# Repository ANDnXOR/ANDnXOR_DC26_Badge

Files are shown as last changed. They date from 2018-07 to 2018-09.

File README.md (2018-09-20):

# AND!XOR DC26 Indie Badge

All files related to the badge are posted here. For now we are only releasing the SD card image as well as any updates to the .bin file (for updates to the core badge itself).

To create a new SD card, format the card with FAT32 then copy the contents of SD/ to the SD card.

*Note: due to the large size of some files, git lfs is required: https://git-lfs.github.com/ *

## LULZCODE Support for Atom Editor ##

LULZCODE is supported by Atom using our plugin: https://atom.io/packages/atom-lulzcode

It is only tested to work on Linux as Windows does not play well with YMODEM from the commandline. At AND!XOR we've been using Linux as our daily-driver since the year of the Linux Desktop anyways. And so should you.
 
## Firmware Updates ##

This year's badge is capable of flashing itself over the air (OTA) or from SD card. OTAs will be available at DEF CON at select locations, times and locations TBD.

To update your firmware manually, place `mrmeeseeks.enc.bin` and `mrmeeseeks.enc.bin.sha256` in the root directory of your SD Card. Place the SD Card back into the badge. The badge may reboot itself or you will need to manually restart it to start the OTA process.

The badge's eye will _very slowly_ blink as it flashes itself. When complete, the badge will restart and the files will be deleted. The process should take 1 to 2 minutes. 

To check the firmware version, go to *System --> About*

*NOTE: It is pointless to check the hash in the `.sha256` file. It will not match.*

## Changelog ##

#### v1.3 ####
* Minor tweaks to further improve SD reliability / avoid corruption.

#### v1.2 ####
* Huge SD stability improvements. Bad blocks no longer crash bling, but will drop frames. Bad blocks are still not readable but we no longer crash.
* Updated to latest ESP-IDF 3.1 beta
* Improved usability of menus based on user feedback
* Fixed ADC not-calibrated (battery voltage was incorrect)
* Added BLE peer hello for Trans Ionospheric badge

#### v1.1 ####
* Stability improvements to the SD Card driver at the expense of some FPS
* Minor improvements to usability of the Pick Name UI
* Thank you to the beta testers for the honest and plentiful feedback of SD card issues. Quality of the SD cards we provided with the badges is poor :( but this firmware update should ensure that good SD cards work properly

#### v1.0 ####
* Initial Release, all Kickstarters received this version

## Known Issues ##

* Voltage displayed on main menu title bar is not accurate
* SD Cards with many bad sectors crash badge (reboot) or exit bling to menu
* Some CHIP8 games do not run

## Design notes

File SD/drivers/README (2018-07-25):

For convenience, drivers for the USB to Serial IC we used are contained here. In the event you do trust us, this will save you some time downloading drivers yourself.

If you don't trust us, you shouldn't, download the CP2102N drivers from silabs.

For Linux, drivers are included. Just need appropriate permissions on the /dev/tty* device and a udev rule. See: https://www.silabs.com/community/interface/knowledge-base.entry.html/2016/06/06/fixed_tty_deviceass-XzTf

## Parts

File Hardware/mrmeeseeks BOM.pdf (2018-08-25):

# AND!XOR DC26 BOM

Designator | Package | Quantity | Designation
U38 | ESP32-WROVER | 1 ESP32 WROVER
R11 | 0402 | 11M Ω
C1,C3,C5,C7,C8,C10,C 18,C19,C22,C25,C26 | 0402 | 110.1uF
C2,C4,C6,C9,C11,C12, C15,C16,C17,C20,C24, C28,C29 | 1206 | 1310uF
C13,C14,C21,C23,C27 | 0402 | 51uF
CON1 | MicroSD | 1 Micro SD Holder
L1 | 1008 | 1 CVH252009-4R7M
R2,R3,R6,R13,R27,R28 ,R26,R16,R22,R23,R24, R25 | 0402 | 1210k Ω
R5 | 0402 | 1470 Ω
R14 | 0402 | 120k Ω
R15 | 0402 | 1100k Ω
Q1,Q2 | SOT-23 | 2 MMBT3904
U36 | SOT-23-6 | 1 AAT1217IGU-3.3-T1
U37 | SOT-223 | 1LM1117IMP-3.3/NOPB
SW10 | JS202011SCQN | 1JS202011SCQN
J1 | MicroUSB | 110118193-0001LF
D1 | 0805 | 1 Red LED
SW1,SW2,SW3,SW4,S W5,SW6,SW7 | 4.2MM | 7 PTS810 SJK
U41 | LGA-12_2x2mm_Pitch0.5mm | 1LIS2DE12TR
U15 | QFN-28-1EP_5x5mm_Pitch0.5mm | 1 CP2102N-A01-GQFN28
U39 | QFN-40-1EP_5x5mm_Pitch0.4mm | 1IS31FL3736
U5 | QFN20 | 1 SLG4AD42405
R12,R7,R8,R9,R10 | 0402 | 51k Ω
E3,E1,E2 | SOD-882L | 3LXES15AAA1-133
R18 | 0402 | 122.1k Ω
R19 | 0402 | 147.5k Ω
BT1 | 2AA-Holder-12BH321P-GR | 112BH321P-GR
U10,U4,U8,U17,U28,U9 ,U13,U19,U23,U27,U31, U35,U3,U2,U18,U22,U2 6,U30,U34,U7,U1,U11, U20,U21,U25,U29,U33, U6,U16,U24,U12 | 1616 | 31LED RGB Common Anode
R17 | 0805 | 1100 Ω
J4 | 15 pin – custom | 1tm020GDHG02

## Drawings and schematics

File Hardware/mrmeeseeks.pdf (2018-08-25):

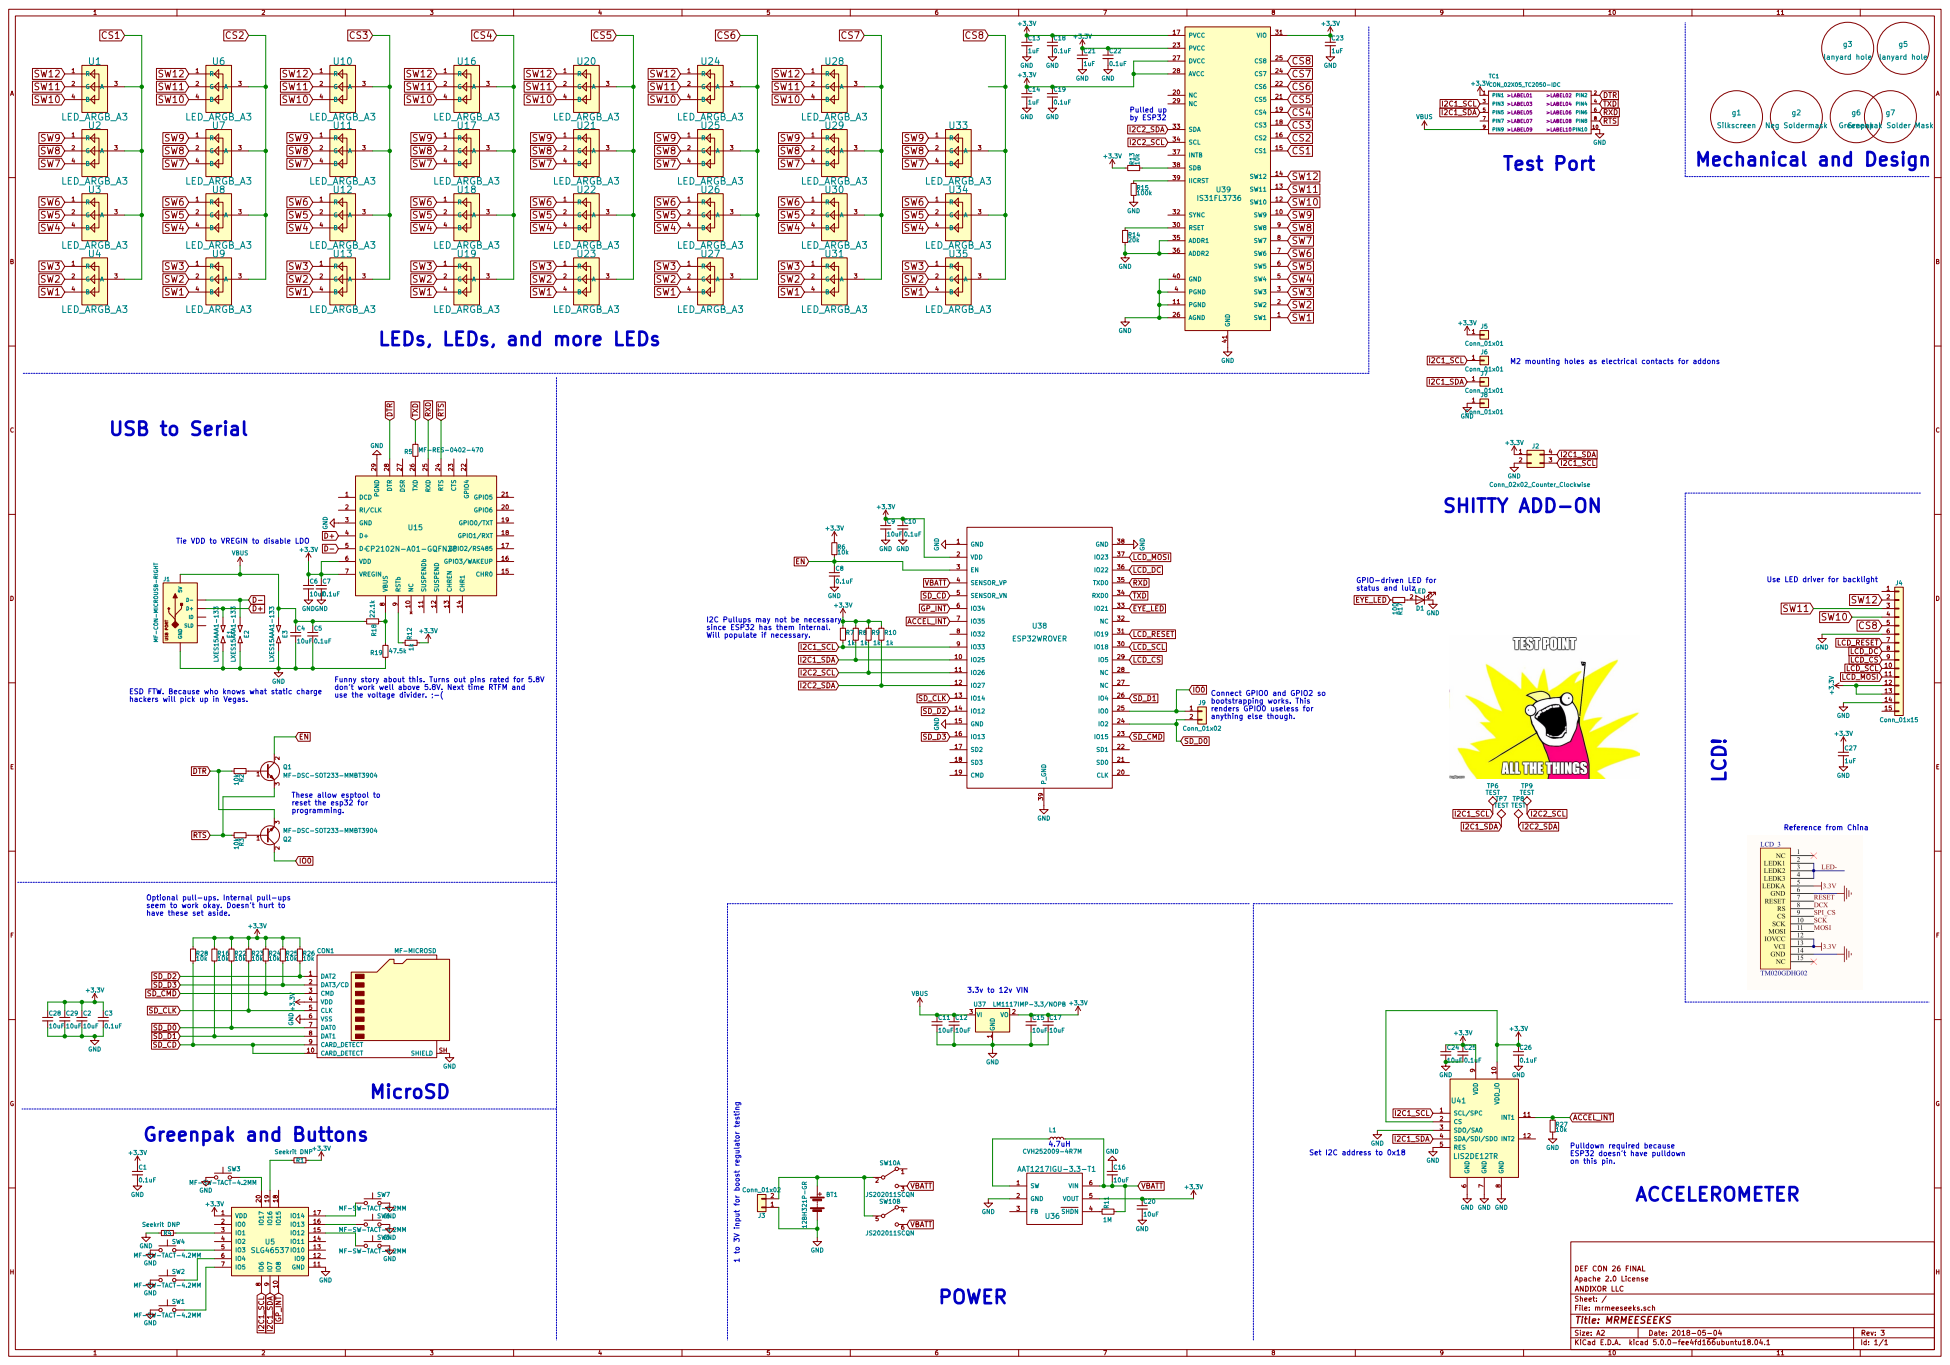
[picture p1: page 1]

+3.3V GND LEDs, LEDs, and more LEDs

+3.3V GND SHITTY ADD-ON

9 U15 CP2102N-A01-GQFN28 R18 22.1k R19 47.5k +3.3V GNDGND Tie VDD to VREGIN to disable LDO

J1 MF-CON-MICROUSB-RIGHT

I2C Pullups may not be necessary
since ESP32 has them internal.

LCD_SCL 1 to 3V input for boost regulator testing

Funny story about this. Turns out pins rated for 5.8V
don't work well above 5.8V. Next time RTFM and use the voltage divider. ;-(

ESD FTW. Because who knows what static charge
hackers will pick up in Vegas.

These allow esptool to
reset the esp32 for

10k +3.3V Optional pull-ups. Internal pull-ups
seem to work okay. Doesn't hurt to
have these set aside.

R1 Seekrit DNP R4 Seekrit DNP GND

GND Set I2C address to 0x18

Apache 2.0 License DEF CON 26 FINAL

File: mrmeeseeks.sch Sheet: / AND!XOR LLC

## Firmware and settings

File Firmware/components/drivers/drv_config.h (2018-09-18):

/*****************************************************************************
 * Made with beer and late nights in California.
 *
 * (C) Copyright 2017-2018 AND!XOR LLC (http://andnxor.com/).
 *
 * PROPRIETARY AND CONFIDENTIAL UNTIL AUGUST 7th, 2018 then,
 *
 * Licensed under the Apache License, Version 2.0 (the "License");
 * you may not use this file except in compliance with the License.
 * You may obtain a copy of the License at
 *
 *     http://www.apache.org/licenses/LICENSE-2.0
 *
 * Unless required by applicable law or agreed to in writing, software
 * distributed under the License is distributed on an "AS IS" BASIS,
 * WITHOUT WARRANTIES OR CONDITIONS OF ANY KIND, either express or implied.
 * See the License for the specific language governing permissions and
 * limitations under the License.
 *
 * ADDITIONALLY:
 * If you find this source code useful in anyway, use it in another electronic
 * conference badge, or just think it's neat. Consider buying us a beer
 * (or two) and/or a badge (or two). We are just as obsessed with collecting
 * badges as we are in making them.
 *
 * Contributors:
 * 	@andnxor
 * 	@zappbrandnxor
 * 	@hyr0n1
 * 	@exc3ls1or
 * 	@lacosteaef
 * 	@bitstr3m
 *****************************************************************************/
#include "system.h"

#ifndef BUILD_DRV_CONFIG_H_
#define BUILD_DRV_CONFIG_H_

#define LCD_PIN_MOSI 23
#define LCD_PIN_CLK 18
#define LCD_PIN_CS 5
#define LCD_PIN_DC 22

#ifndef CONFIG_BADGE_TYPE_STANDALONE
#define LCD_PIN_RST 19
#define LED_EYE_PIN 21
#endif

#define I2C_1_FREQ_HZ 400000
#define I2C_2_FREQ_HZ 400000
#define I2C_1_SDA 25
#define I2C_1_SCL 33
#define I2C_2_SDA 27
#define I2C_2_SCL 26
#define I2C_MASTER_RX_BUF_DISABLE 0
#define I2C_MASTER_TX_BUF_DISABLE 0
#define I2C_MAX_DELAY 100

#define LED_I2C_ADDR ISSI_ADDR_DEFAULT
#define LED_I2C_MASTER_NUM I2C_NUM_1

#define ACCEL_I2C_ADDR_1 0x18
#define ACCEL_I2C_ADDR_2 0x19
#define ACCEL_I2C_MASTER_NUM I2C_NUM_0
#define ACCEL_ISR_GPIO 35
#define ACCEL_ISR_GPIO_MASK GPIO_SEL_35

#define GREENPAK_I2C_ADDR 0x30
#define GREENPAK_I2C_MASTER_NUM I2C_NUM_0

#define ADDON_I2C_MASTER_NUM I2C_NUM_0

// SD Card in SPI mode
#define SD_PIN_MISO 2
#define SD_PIN_MOSI 15
#define SD_PIN_CLK 14
#define SD_PIN_CS 13

#define SD_CARD_DETECT 39

#endif /* BUILD_DRV_CONFIG_H_ */

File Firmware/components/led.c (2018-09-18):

/*****************************************************************************
 * Made with beer and late nights in California.
 *
 * (C) Copyright 2017-2018 AND!XOR LLC (http://andnxor.com/).
 *
 * PROPRIETARY AND CONFIDENTIAL UNTIL AUGUST 7th, 2018 then,
 *
 * Licensed under the Apache License, Version 2.0 (the "License");
 * you may not use this file except in compliance with the License.
 * You may obtain a copy of the License at
 *
 *     http://www.apache.org/licenses/LICENSE-2.0
 *
 * Unless required by applicable law or agreed to in writing, software
 * distributed under the License is distributed on an "AS IS" BASIS,
 * WITHOUT WARRANTIES OR CONDITIONS OF ANY KIND, either express or implied.
 * See the License for the specific language governing permissions and
 * limitations under the License.
 *
 * ADDITIONALLY:
 * If you find this source code useful in anyway, use it in another electronic
 * conference badge, or just think it's neat. Consider buying us a beer
 * (or two) and/or a badge (or two). We are just as obsessed with collecting
 * badges as we are in making them.
 *
 * Contributors:
 * 	@andnxor
 * 	@zappbrandnxor
 * 	@hyr0n1
 * 	@exc3ls1or
 * 	@lacosteaef
 * 	@bitstr3m
 *****************************************************************************/
#include "system.h"

#ifndef CONFIG_BADGE_TYPE_STANDALONE
#define LED_EYE_DUTY 4000
#define LED_EYE_DUTY_MAX 5000

static ledc_channel_config_t ledc_channel = {.channel = LEDC_CHANNEL_0,
                                             .duty = 0,
                                             .gpio_num = LED_EYE_PIN,
                                             .speed_mode = LEDC_HIGH_SPEED_MODE,
                                             .timer_sel = LEDC_TIMER_0};
#endif

#define LED_COUNT_INTERNAL 32

static const uint8_t gamma_values[] = {
    0,   0,   0,   0,   0,   0,   0,   0,   0,   0,   0,   0,   0,   0,   0,
    0,   0,   0,   0,   0,   0,   0,   0,   0,   0,   0,   0,   0,   1,   1,
    1,   1,   1,   1,   1,   1,   1,   1,   1,   1,   1,   2,   2,   2,   2,
    2,   2,   2,   2,   3,   3,   3,   3,   3,   3,   3,   4,   4,   4,   4,
    4,   5,   5,   5,   5,   6,   6,   6,   6,   7,   7,   7,   7,   8,   8,
    8,   9,   9,   9,   10,  10,  10,  11,  11,  11,  12,  12,  13,  13,  13,
    14,  14,  15,  15,  16,  16,  17,  17,  18,  18,  19,  19,  20,  20,  21,
    21,  22,  22,  23,  24,  24,  25,  25,  26,  27,  27,  28,  29,  29,  30,
    31,  32,  32,  33,  34,  35,  35,  36,  37,  38,  39,  39,  40,  41,  42,
    43,  44,  45,  46,  47,  48,  49,  50,  50,  51,  52,  54,  55,  56,  57,
    58,  59,  60,  61,  62,  63,  64,  66,  67,  68,  69,  70,  72,  73,  74,
    75,  77,  78,  79,  81,  82,  83,  85,  86,  87,  89,  90,  92,  93,  95,
    96,  98,  99,  101, 102, 104, 105, 107, 109, 110, 112, 114, 115, 117, 119,
    120, 122, 124, 126, 127, 129, 131, 133, 135, 137, 138, 140, 142, 144, 146,
    148, 150, 152, 154, 156, 158, 160, 162, 164, 167, 169, 171, 173, 175, 177,
    180, 182, 184, 186, 189, 191, 193, 196, 198, 200, 203, 205, 208, 210, 213,
    215, 218, 220, 223, 225, 228, 231, 233, 236, 239, 241, 244, 247, 249, 252,
    255};

const static unsigned char led_address[LED_COUNT_INTERNAL][3] = {
    {0x00, 0x10, 0x20}, {0x02, 0x12, 0x22}, {0x04, 0x14, 0x24},
    {0x06, 0x16, 0x26}, {0x08, 0x18, 0x28}, {0x0A, 0x1A, 0x2A},
    {0x0C, 0x1C, 0x2C}, {0x0E, 0x1E, 0x2E}, {0x30, 0x40, 0x50},
    {0x32, 0x42, 0x52}, {0x34, 0x44, 0x54}, {0x36, 0x46, 0x56},
    {0x38, 0x48, 0x58}, {0x3A, 0x4A, 0x5A}, {0x3C, 0x4C, 0x5C},
    {0x3E, 0x4E, 0x5E}, {0x60, 0x70, 0x80}, {0x62, 0x72, 0x82},
    {0x64, 0x74, 0x84}, {0x66, 0x76, 0x86}, {0x68, 0x78, 0x88},
    {0x6A, 0x7A, 0x8A}, {0x6C, 0x7C, 0x8C}, {0x6E, 0x7E, 0x8E},
    {0x90, 0xA0, 0xB0}, {0x92, 0xA2, 0xB2}, {0x94, 0xA4, 0xB4},
    {0x96, 0xA6, 0xB6}, {0x98, 0xA8, 0xB8}, {0x9A, 0xAA, 0xBA},
    {0x9C, 0xAC, 0xBC}, {0x9E, 0xAE, 0xBE}
    /*{ 0x9E, 0xAE, 0xBE }*/
};

const static char* TAG = "MRMEESEEKS::LED";

unsigned char led_memory[ISSI_ADDR_MAX];
static volatile uint16_t m_led_eye_blink_delay = 1000;
static uint8_t m_brightness = 10;
static bool m_led_eye_blink_run = false;
static bool m_led_eye_pulse_run = false;

void __blink_eye_task(void* params) {
  m_led_eye_blink_run = true;
  while (m_led_eye_blink_run) {
    led_eye_set(true);
    DELAY(m_led_eye_blink_delay);
    led_eye_set(false);
    DELAY(m_led_eye_blink_delay);
  }

  vTaskDelete(NULL);
}

void __pulse_eye_task(void* params) {
  ESP_LOGD(TAG, "Starting eye LED task");
  m_led_eye_pulse_run = true;
  int16_t brightness = 0;
  int8_t delta = 1;

  while (m_led_eye_pulse_run) {
    led_eye_pwm(brightness);
    brightness += delta;
    DELAY(50);

    if (brightness >= 70) {
      delta = -1;
    } else if (brightness < 0) {
      delta = 1;
    }

    if (brightness < 0) {
      brightness = 0;
    }
  }
  vTaskDelete(NULL);
}

uint8_t led_brightness_get() {
  return m_brightness;
}

void led_brightness_set(uint8_t brightness) {
  m_brightness = brightness;
  drv_is31fl_gcc_set(m_brightness);
}

void led_clear() {
  led_set_all(0, 0, 0);
  led_show();
}

void led_eye_blink_delay(uint16_t delay) {
  m_led_eye_blink_delay = delay;
}

void led_eye_blink_start() {
  if (!m_led_eye_blink_run) {
    xTaskCreatePinnedToCore(&__blink_eye_task, "Eye LED Blink", 4096, NULL,
                            TASK_PRIORITY_LOW, NULL, APP_CPU_NUM);
  }
}

void led_eye_blink_stop() {
  m_led_eye_blink_run = false;
}

void led_eye_pwm(uint8_t brightness) {
#ifndef CONFIG_BADGE_TYPE_STANDALONE
  float percent = (float)brightness / 255.0;
  uint16_t new_value = (uint16_t)(percent * LED_EYE_DUTY_MAX);
  ledc_set_duty(ledc_channel.speed_mode, ledc_channel.channel, new_value);
  ledc_update_duty(ledc_channel.speed_mode, ledc_channel.channel);
#endif
}

void led_eye_set(bool high) {
#ifndef CONFIG_BADGE_TYPE_STANDALONE
  gpio_set_level(LED_EYE_PIN, high);
#endif
}

void led_eye_init() {
#ifndef CONFIG_BADGE_TYPE_STANDALONE
  gpio_set_direction(LED_EYE_PIN, GPIO_MODE_OUTPUT);
#endif
}

void led_eye_pulse_start() {
#ifndef CONFIG_BADGE_TYPE_STANDALONE
  xTaskCreatePinnedToCore(&__pulse_eye_task, "Eye LED Pulse", 4096, NULL,
                          TASK_PRIORITY_LOW, NULL, APP_CPU_NUM);
#endif
}

void led_eye_pulse_stop() {
  m_led_eye_pulse_run = false;
}

void led_init() {
  drv_is31fl_init();
  for (uint8_t i = 0; i < ISSI_ADDR_MAX; i++) {
    led_memory[i] = 0;
  }
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

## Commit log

2018-07-25 SD Card Image
    [ANDNXOR.cfg, Airplane.cfg, Alien.cfg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]
2018-08-01 Alien crashes our CHIP8 emulator :(
    [Alien.cfg]
2018-08-25 Gerbers, BOM, and Schematic
    [mrmeeseeks-B.Cu.gbl, mrmeeseeks-B.Mask.gbs, mrmeeseeks-B.Paste.gbp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]
2018-09-18 Final 1.3 source code.
    [partitions.csv]
2019-01-26 You asked for it
    [bandana-B.Cu.gbl, bandana-B.Mask.gbs, bandana-B.Paste.gbp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]
